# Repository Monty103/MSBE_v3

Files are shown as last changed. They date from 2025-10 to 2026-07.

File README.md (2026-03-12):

## MSBE_v3

An ultra-compact, low-power wearable audio device featuring bone-conduction technology, digital PDM voice capture, and multi-gesture touch controls.

---

## 🏗️ Core Component Architecture

| Component | Part Number | Function | Interface |
| :--- | :--- | :--- | :--- |
| **Main MCU** | **nRF5340-CLAA-R** | Dual-core Bluetooth 5.4 SoC (App & Network) | N/A |
| **PMIC** | **nPM1100** | Battery charging & high-efficiency power regulation | Analog/NTC |
| **Audio Driver** | **MAX98357A (x2)** | Class D I2S Amp for Bone Conduction Speakers | I2S |
| **Microphone** | **SPH18R1LM4H-1** | Digital MEMS Microphone for Voice/Calls | PDM |
| **Motion Sensor** | **BMA400** | Ultra-low power accelerometer (Proximity/Wake-up) | I2C |
| **Touch Controller**| **MPR121** | 12-Channel Capacitive Touch (Slider/Gestures) | I2C |

---

## ⚡ System Design Details

### 1. Processing (nRF5340)
The **Application Core** handles the I2S audio stream and gesture logic from the MPR121, while the **Network Core** manages the Bluetooth Low Energy (BLE) stack. 
* **Key Config:** Uses Port 1 for high-speed audio to isolate switching noise.

### 2. Audio Output (MAX98357A)
Two drivers are utilized to provide a stereo bone-conduction experience. These chips convert the digital I2S signal from the nRF5340 directly into analog power for the transducers.
* **Feature:** Filterless Class D, ideal for compact wearable PCB routing.

### 3. Voice Input (SPH18R1LM4H-1)
A high-performance PDM microphone. It operates in multiple power modes (Sleep, Low-Power, Normal) controlled dynamically by the nRF5340’s clock frequency to preserve battery life.

### 4. Power Management (nPM1100)
The PMIC ensures maximum battery life using a high-efficiency buck regulator. 
* **Safety:** Integrated Li-Po charger with JEITA thermal monitoring via a 10k NTC thermistor.
* **Form Factor:** Optimized for WLCSP-style compact assembly.

### 5. Interaction (BMA400 & MPR121)
* **BMA400:** Acts as a "wear-detect" sensor. It triggers an interrupt to wake the system when the headset is moved or put on.
* **MPR121:** Connected to a 3-pad copper slider on the PCB. It supports:
    * **Single/Double Tap:** Play/Pause/Assistant.
    * **Swipe Left/Right:** Volume and Track control via a state-machine on the nRF5340.

---

## 🛠️ Pin Mapping Summary

| Signal | nRF5340 Pin | Hardware Pin | Shared Bus |
| :--- | :--- | :--- | :--- |
| **I2C SCL** | **P0.04** | BMA400 (12) / MPR121 (3) | Yes |
| **I2C SDA** | **P0.05** | BMA400 (2) / MPR121 (4) | Yes |
| **PDM CLK** | **P0.26** | Mic (Clock) | No |
| **PDM DATA** | **P0.25** | Mic (Data) | No |
| **I2S SCK** | **P1.12** | MAX98357A (BCLK) | Yes |
| **I2S LRCLK** | **P1.13** | MAX98357A (WS) | Yes |
| **I2S SDOUT** | **P1.14** | MAX98357A (Din) | Yes |
| **BMA INT** | **P0.06** | BMA400 (INT1) | No |
| **Touch IRQ** | **P0.08** | MPR121 (IRQ) | No |

---

## 📋 Hardware Implementation Notes
* **Touch Slider:** 3-electrode design (ELE0, ELE1, ELE2) for swipe detection.
* **Mic Configuration:** SEL pin tied to GND for mono/left channel timing.
* **I2C Mode:** MPR121 CSB pin must be tied to VDDIO to enable I2C communication.
* **Power Rail:** All sensors and MCU peripherals are powered via the 1.8V VOUT from the nPM1100.

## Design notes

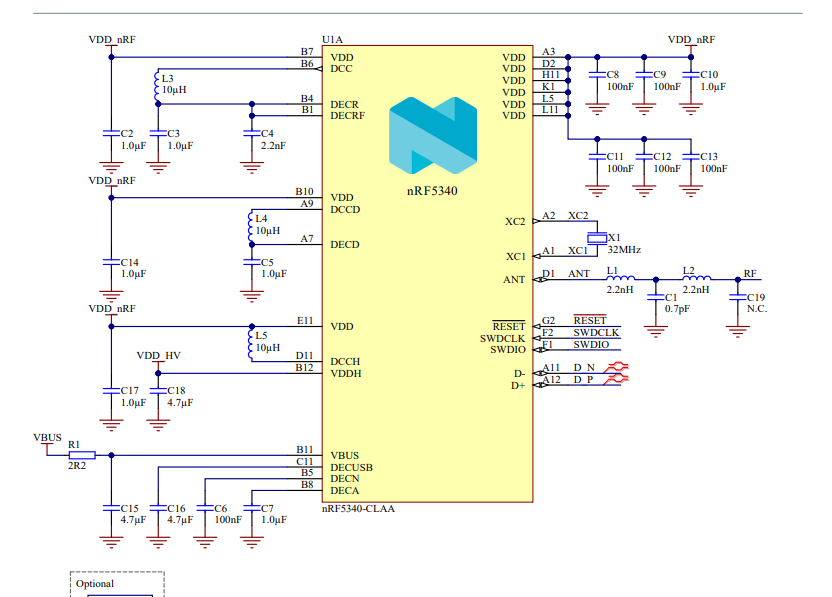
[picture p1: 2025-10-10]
hardware/references/Screenshot_8.png

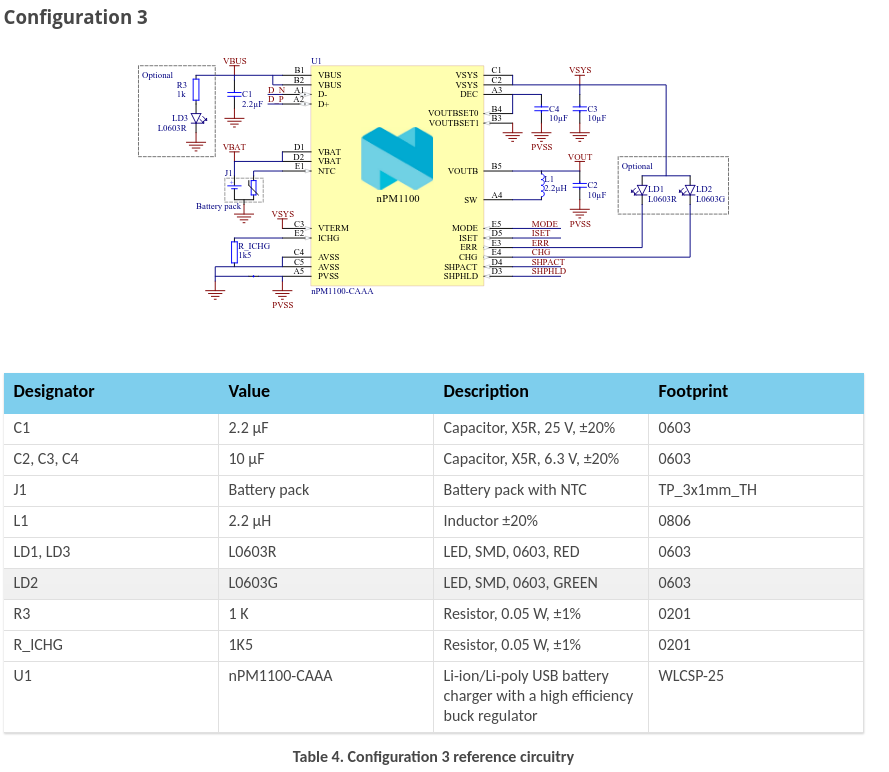
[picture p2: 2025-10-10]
hardware/references/pastedimage1660503774932v3.png

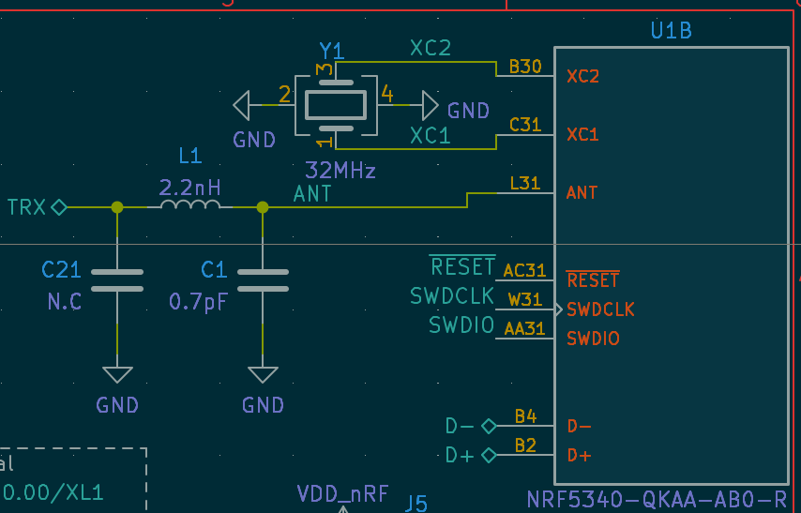
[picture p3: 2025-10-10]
hardware/references/pastedimage1660504782283v7.png

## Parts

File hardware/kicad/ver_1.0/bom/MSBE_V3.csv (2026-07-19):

Reference | Qty | Value | DNP | Exclude from BOM | Exclude from Board | Footprint | Datasheet
AE1 | 1 | Antenna_Shield |  |  |  | RF_Antenna:Texas_SWRA117D_2.4GHz_Left | ~
BT1 | 1 | Battery_Cell |  |  |  | myLib:Pad_3Pin_1.5x0.8mm | ~
C1,C10,C11,C18,C30,C31,C33,C34,C35,C36,C37,C38 | 12 | 100nF |  |  |  | Capacitor_SMD:C_0603_1608Metric | ~
C2,C9,C23 | 3 | 0.1uF |  |  |  | Capacitor_SMD:C_0603_1608Metric | ~
C3,C4,C5 | 3 | N.M. |  |  |  | Capacitor_SMD:C_0603_1608Metric | ~
C6 | 1 | 0.7pF |  |  |  | Capacitor_SMD:C_0603_1608Metric | ~
C7,C8 | 2 | 12pF |  |  |  | Capacitor_SMD:C_0603_1608Metric | ~
C12,C13,C15,C17,C20 | 5 | 1uF |  |  |  | Capacitor_SMD:C_0603_1608Metric | ~
C14,C16,C21 | 3 | 4.7uF |  |  |  | Capacitor_SMD:C_0603_1608Metric | ~
C19 | 1 | 2.2nF |  |  |  | Capacitor_SMD:C_0603_1608Metric | ~
C25,C26,C27,C28 | 4 | 10uF |  |  |  | Capacitor_SMD:C_0603_1608Metric | ~
C32 | 1 | 47uF |  |  |  | Capacitor_SMD:C_0603_1608Metric | ~
C42,C45,C49,C50,C51 | 5 | 30pF |  |  |  | Capacitor_SMD:C_0603_1608Metric | ~
D1,D2 | 2 | LED |  |  |  | LED_SMD:LED_0603_1608Metric | ~
J1 | 1 | USB_C_Receptacle_USB2.0_16P |  |  |  | Connector_USB:USB_C_Receptacle_GCT_USB4110 | https://www.usb.org/sites/default/files/documents/usb_type-c.zip
J2 | 1 | Touch Pads |  |  |  | myLib:Pad_3Pin_1.5x0.8mm | ~
J3 | 1 | UART |  |  |  | myLib:Pad_3Pin_1.5x0.8mm | ~
J4 | 1 | Prog |  |  |  | myLib:Pad_prog_4Pad | ~
J6 | 1 | High-V |  |  |  | myLib:Pad_prog_4Pad | ~
J8 | 1 | Low-V |  |  |  | myLib:Pad_prog_4Pad | ~
J9 | 1 | Low-V-TH |  |  |  | Connector_PinHeader_2.54mm:PinHeader_1x05_P2.54mm_Vertical | ~
L1 | 1 | N.M. |  |  |  | Inductor_SMD:L_0603_1608Metric | ~
L2 | 1 | 2.2nH |  |  |  | Inductor_SMD:L_0603_1608Metric | ~
L3,L4 | 2 | 10uH |  |  |  | Inductor_SMD:L_0603_1608Metric | ~
L5 | 1 | 2.2uH |  |  |  | Inductor_SMD:L_0603_1608Metric | ~
LS1 | 1 | SPH18R1LM4H-1-8 |  |  |  | myLib:MIC_SPH18R1LM4H_KNO | SPH18R1LM4H-1-8
LS4,LS5 | 2 | Boneconduction |  |  |  | myLib:Pad_2Pin_1.5x0.8mm | ~
R1 | 1 | 75k |  |  |  | Resistor_SMD:R_0603_1608Metric | ~
R2,R3,R5 | 3 | 5K1R |  |  |  | Resistor_SMD:R_0603_1608Metric | ~
R4 | 1 | 2R2 |  |  |  | Resistor_SMD:R_0603_1608Metric | ~
R6 | 1 | 10K |  |  |  | Resistor_SMD:R_0603_1608Metric | ~
R8 | 1 | N.C. |  |  |  | Resistor_SMD:R_0603_1608Metric | ~
R9,R10 | 2 | 4k7 |  |  |  | Resistor_SMD:R_0603_1608Metric | ~
R11,R12 | 2 | 1K5R |  |  |  | Resistor_SMD:R_0603_1608Metric | ~
R14,R15,R18,R22,R23 | 5 | 1K5 |  |  |  | Resistor_SMD:R_0603_1608Metric | ~
R16,R17,R19,R24,R25 | 5 | 1K8 |  |  |  | Resistor_SMD:R_0603_1608Metric | ~
R34 | 1 | 680k |  |  |  | Resistor_SMD:R_0603_1608Metric | ~
U1 | 1 | BMA400 |  |  |  | myLib:QFN_BMA400_BOS | BMA400
U2 | 1 | MPR121QR2 |  |  |  | myLib:MPR121 | MPR121QR2
U3 | 1 | NRF5340-QKAA-R |  |  |  | myLib:NRF5340
U4 | 1 | NPM1100-CAAA-R7 |  |  |  | myLib:NPM1100-CAAA-BGA25C40P5X5_207X207X52N
U6 | 1 | MAX98357AEWL_T |  |  |  | myLib:MAX98357A_BGA9N40P3X3_134X143X69N
Y1 | 1 | 32MHz |  |  |  | myLib:ECS-160-10-37-JTN-TR_ECS | ~
Y2 | 1 | 32.768kHz |  |  |  | myLib:Crystal_24MHz-ECS-240-12-37B-CKY-TR | ~

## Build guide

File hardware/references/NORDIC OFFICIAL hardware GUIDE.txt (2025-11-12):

https://docs.nordicsemi.com/bundle/ug_nrf5340_audio/page/UG/nrf5340_audio/hw_audio_codec.html

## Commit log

2026-03-12 Added kicad schematic and routed all. Next needed to make PCB
    [MSBE_V3.kicad_pcb, MSBE_V3.kicad_sch]
2026-05-01 updated all
    [MSBE_V3.kicad_pcb, MSBE_V3.kicad_sch]
2026-05-07 new stuff added
    [MSBE_V3.kicad_sch, untitled.kicad_sch]
2026-05-12 modified schematic only
    [MSBE_V3.kicad_sch]
2026-05-26 new chip package
    [MSBE_V3.kicad_sch, MSBE_V3_1.kicad_sch]
2026-05-27 updated schematic QFN
    [MSBE_V3.kicad_sch, MSBE_V3_1.kicad_sch]
2026-06-02 update 2
    [MSBE_V3.kicad_pcb, MSBE_V3.kicad_sch]
2026-07-11 izmene 7.11
    [MSBE_V3.kicad_pcb, MSBE_V3.kicad_sch, untitled.kicad_sch]
2026-07-14 done with PCB, need to import to easy eda for better routign
    [MSBE_V3.kicad_pcb]
2026-07-17 start of routing
    [MSBE_V3.kicad_pcb, MSBE_V3.kicad_sch]
2026-07-19 final, next is to order
    [MSBE_V3-B_Cu.gbr, MSBE_V3-B_Mask.gbr, MSBE_V3-B_Paste.gbr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]
2026-09-24 pgrogress until decision to switch to 6-layer board
2026-09-25 continuing the idea of 6 layer board
2026-10-16 added test for Claude + KiCad
